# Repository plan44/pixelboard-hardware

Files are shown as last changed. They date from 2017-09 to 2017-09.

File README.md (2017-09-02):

# Pixelboard Hardware

The **Pixelboard** is a 80*40cm lounge table board only 24mm thick, integrating a 10x20 color pixel matrix, 8 touch keys, a linux controller with WiFi and ethernet and even a power supply. All disguised under a dark plexiglass, looking like a regular lounge table until touched...

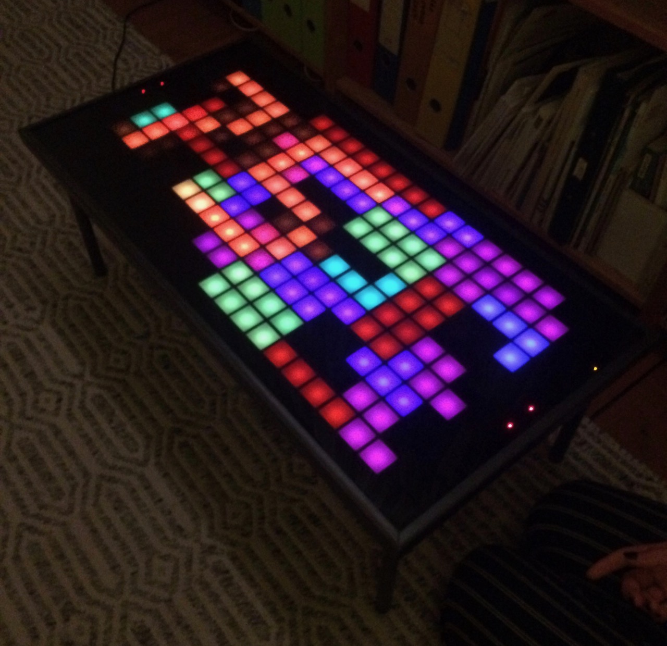
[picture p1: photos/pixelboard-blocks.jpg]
Pixelboard at night

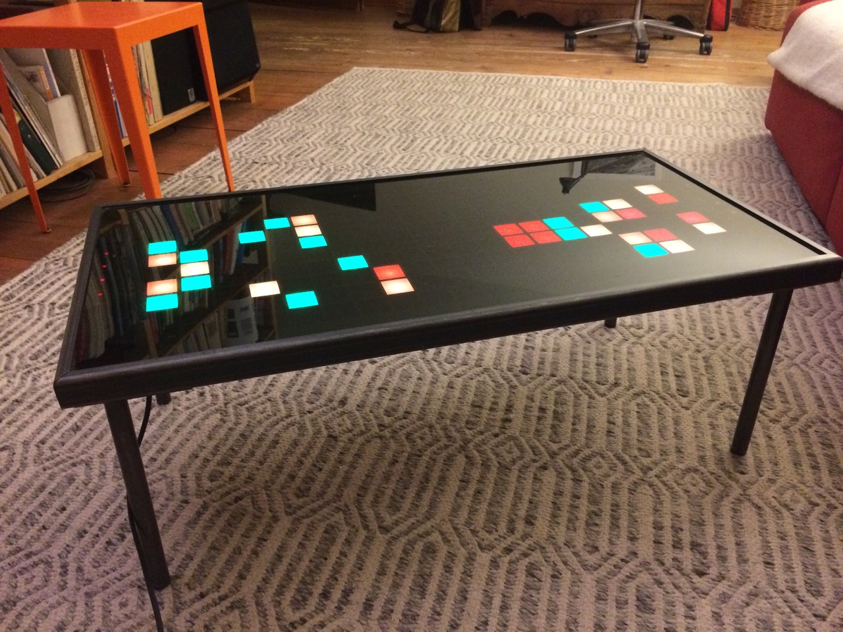
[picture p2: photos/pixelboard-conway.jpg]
Pixelboard daytime


With the current software (see [pixelboardd](https://github.com/plan44/pixelboardd) and [pixelboard-config in plan44-feed](https://github.com/plan44/plan44-feed/tree/for-lede-master/pixelboard-config)) you can play tetris (alone or 2 players each on one end of the board), watch Conway's game of life, let text messages scroll over the surface and display small 10x20 pixel PNG images (via web interface).

The board itself is made of 5 layers of lasered plywood and plexiglass. The construction plan is a [Affinity Designer](https://affinity.serif.com/en-us/designer/) drawing in `mechanics/` and there are SVG exports of the layers in `mechanics/exported SVGs for laser/`.

The pixels are made of 33mm spaced WS2813 LED strips, arranged in a 10*20 matrix, all power and data lines connected by two narrow PCBs (see KiCAD files in `electronics/connectorboard`, PCBs can be [ordered here](https://oshpark.com/shared_projects/2NEbDGZJ)). The board is designed such that it works for both sides of the matrix (flipped over at the far end).

The control board is built around a [Onion Omega2](https://onion.io/omega2/), a MediaTek MT7688 based MIPS board with built-in WiFi, 64MB RAM and 16MB Flash, running a LEDE/OpenWRT Linux based firmware (see [here](https://github.com/plan44/plan44-feed/blob/for-lede-master/pixelboard-config/README.md) for how to build the firmware from scratch). The KiCAD files are in `electronics/controlboard`, PCBs can be [ordered here](https://oshpark.com/shared_projects/cvgoJ8vJ)).

The two identical touch key boards are based on the AT42QT1070 chip for handling the touch detection plus a i2c port extender for connecting the indicator LEDs placed in the middle under each touch key. The KiCAD files are in `electronics/touchboard`, PCBs can be [ordered here](https://oshpark.com/shared_projects/GfQ63cgI)).

And in `photos` there are a few images showing various states of assembling all this:

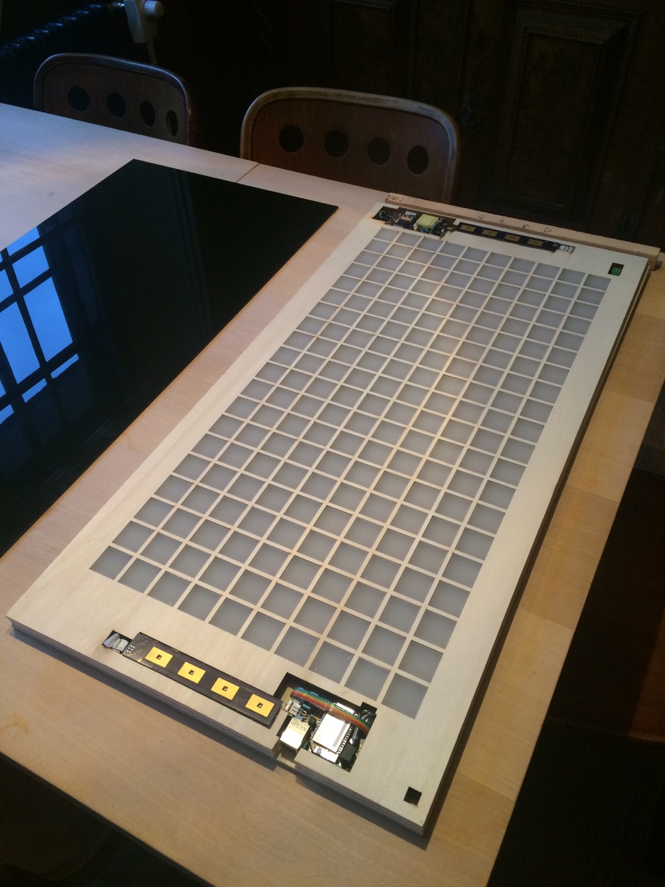
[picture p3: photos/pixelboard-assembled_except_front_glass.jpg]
Without front glass

Front glass removed

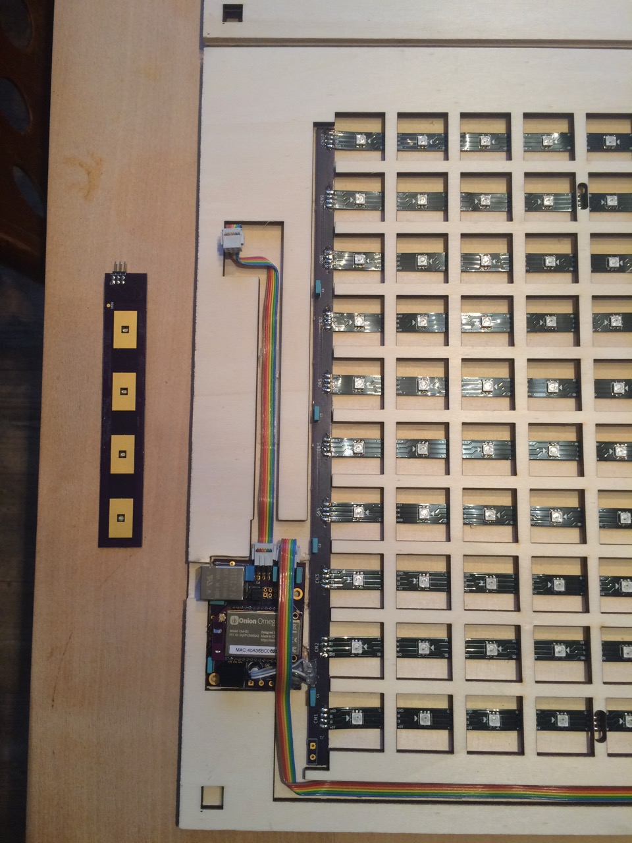
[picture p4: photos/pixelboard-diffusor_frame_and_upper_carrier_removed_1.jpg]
bottom frame only

Controlboard side, just base plate and first lasered frame (lower carrier) keeping the LED matrix, cables, and controlboard in place.

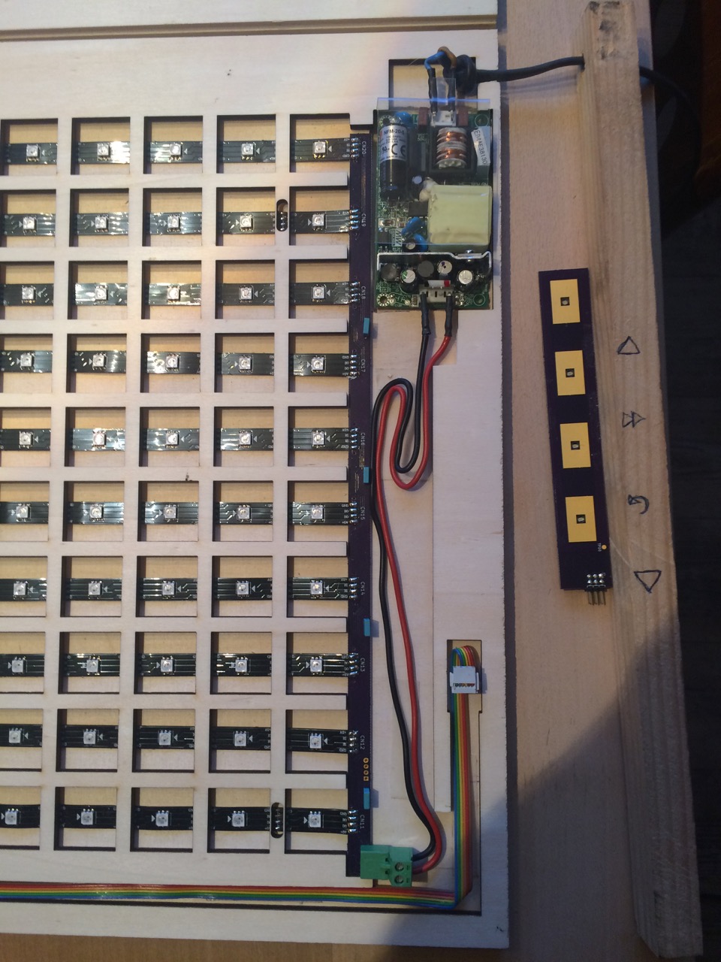
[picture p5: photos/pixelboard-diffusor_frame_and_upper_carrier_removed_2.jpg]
power supply side

Power supply side, base plate and lower carrier.

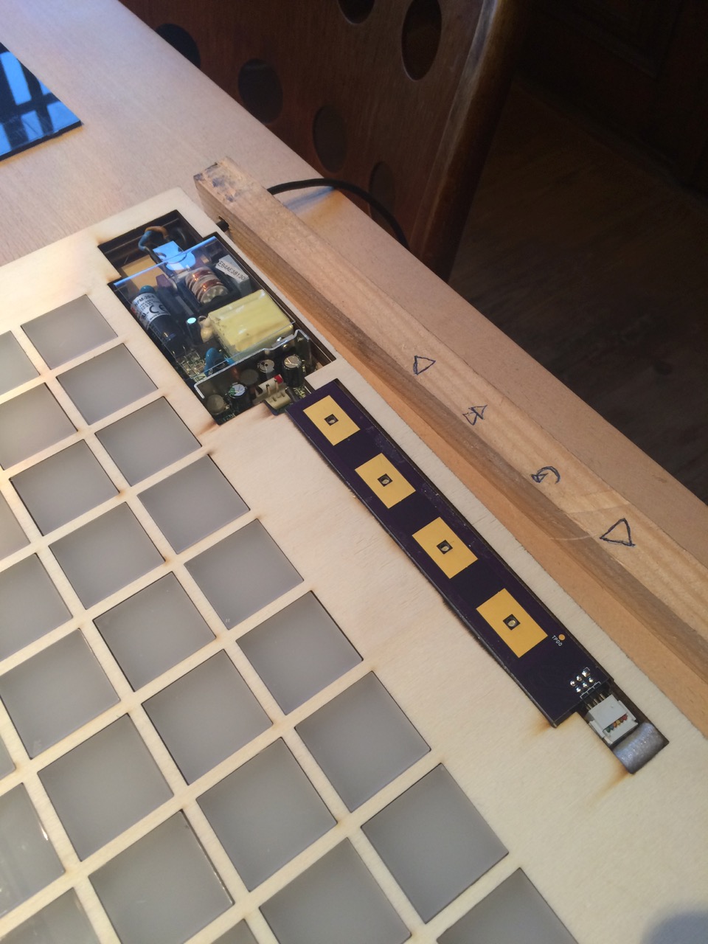
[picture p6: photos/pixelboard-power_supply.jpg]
with touchboard

Power supply side, now with all plywood layers and touchboard mounted.

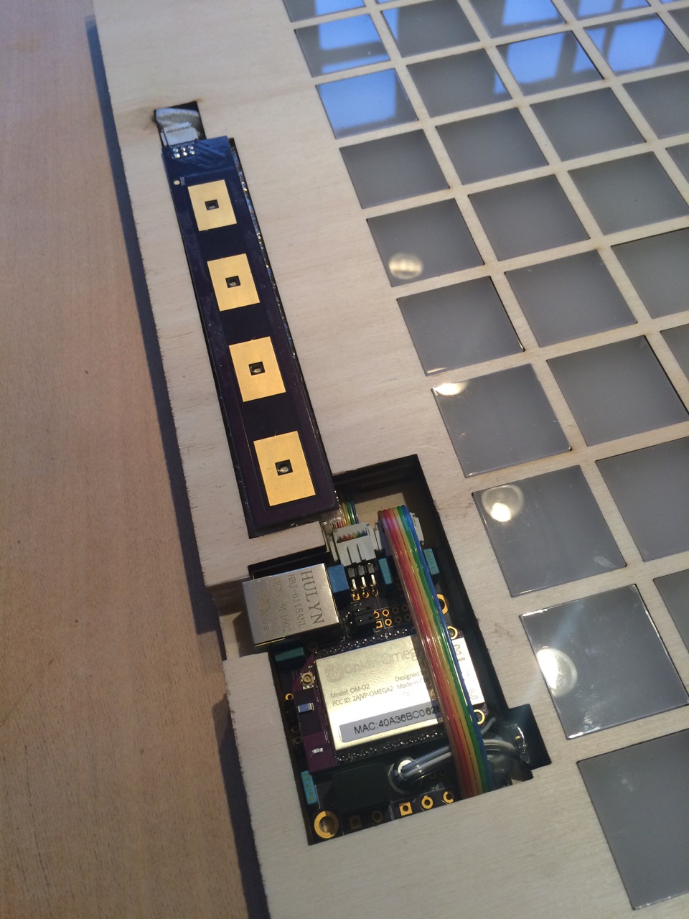
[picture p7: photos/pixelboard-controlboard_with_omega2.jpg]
Controlboard side

Controlboard side, all plywood layers mounted, diffusor plexi sqares inserted, touchboard mounted. Note that this photo does not yet show the hole for a little speaker connected to the MAX98357A i2s amp (but the plan drawings have it).

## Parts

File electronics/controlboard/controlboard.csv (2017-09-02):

Reference | Value | Footprint | Datasheet
U1 | ONION-OMEGA2 | plan44:plan44-ONION-2MM-2X16
J1 | STELVIO-2P-508 | plan44:plan44-STELVIO-2P-508
U2 | Recom_R78Cxx | Converters_DCDC_ACDC:DCDC-Conv_Recom_R-78HBxx-0.5
C5 | 100nF | Capacitors_ThroughHole:C_Rect_L7_W2.5_P5
C3 | 100nF | Capacitors_ThroughHole:C_Rect_L7_W2.5_P5
C4 | 10uF | Capacitors_ThroughHole:C_Radial_D7.5_L11.2_P2.5
P2 | FDI_Cable | Pin_Headers:Pin_Header_Angled_1x06
P3 | CONN_02X03 | Pin_Headers:Pin_Header_Angled_2x03
P4 | CONN_02X03 | Pin_Headers:Pin_Header_Angled_2x03
C1 | 100nF | Capacitors_ThroughHole:C_Rect_L7_W2.5_P5
C2 | 100nF | Capacitors_ThroughHole:C_Rect_L7_W2.5_P5
P1 | CONN_01X04 | Pin_Headers:Pin_Header_Straight_1x04
J3 | HLJ-6115ANL | plan44:plan44-HLJ-6115ANL
P7 | CONN_02X02 | Pin_Headers:Pin_Header_Straight_2x02
C8 | 1uF | Capacitors_ThroughHole:C_Rect_L7_W2.5_P5
R1 | 49.9_1% | Resistors_ThroughHole:Resistor_Horizontal_RM10mm
R2 | 49.9_1% | Resistors_ThroughHole:Resistor_Horizontal_RM10mm
R3 | 49.9_1% | Resistors_ThroughHole:Resistor_Horizontal_RM10mm
R4 | 49.9_1% | Resistors_ThroughHole:Resistor_Horizontal_RM10mm
C6 | 100nF | Capacitors_ThroughHole:C_Rect_L7_W2.5_P5
C7 | 100nF | Capacitors_ThroughHole:C_Rect_L7_W2.5_P5
R5 | 1k | Resistors_ThroughHole:Resistor_Horizontal_RM10mm
R6 | 1k | Resistors_ThroughHole:Resistor_Horizontal_RM10mm
J2 | SBB | plan44:plan44-STELVIO-4P-508
U3 | ADM3485E | SMD_Packages:SOIC-8-N
P6 | CONN_02X03 | Pin_Headers:Pin_Header_Straight_2x03
P5 | CONN_02X05 | Pin_Headers:Pin_Header_Straight_2x05
MH1 | CONN_01X01 | Mounting_Holes:MountingHole_3.2mm_M3_DIN965_Pad
MH2 | CONN_01X01 | Mounting_Holes:MountingHole_3.2mm_M3_DIN965_Pad
U4 | 7400 | Housings_SOIC:SOIC-14_3.9x8.7mm_Pitch1.27mm

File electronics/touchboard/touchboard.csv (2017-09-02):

Reference | Value | Footprint | Datasheet | Family
U1 | AT42QT1070 | SMD_Packages:SOIC-14_N |  | IC
R11 | 4.7k | Resistors_SMD:R_1206_HandSoldering
R2 | 4.7k-20k | Resistors_SMD:R_1206_HandSoldering
R3 | 4.7k | Resistors_SMD:R_1206_HandSoldering
R4 | 4.7k | Resistors_SMD:R_1206_HandSoldering
R5 | 4.7k | Resistors_SMD:R_1206_HandSoldering
R6 | 4.7k | Resistors_SMD:R_1206_HandSoldering
TPD0 | CONN_01X01 | Measurement_Points:Measurement_Point_Round-SMD-Pad_Small
TPD1 | CONN_01X01 | plan44:Touchpad_12x20_with_LED
TPD2 | CONN_01X01 | plan44:Touchpad_12x20_with_LED
TPD3 | CONN_01X01 | plan44:Touchpad_12x20_with_LED
TPD4 | CONN_01X01 | plan44:Touchpad_12x20_with_LED
P1 | CONN_02X03 | Pin_Headers:Pin_Header_Angled_2x03
C1 | C | Capacitors_SMD:C_1206_HandSoldering
R9 | 47k | Resistors_SMD:R_1206_HandSoldering
R13 | 1.2k | Resistors_SMD:R_1206_HandSoldering
R14 | 1.2k | Resistors_SMD:R_1206_HandSoldering
R15 | 1.2k | Resistors_SMD:R_1206_HandSoldering
R16 | 1.2k | Resistors_SMD:R_1206_HandSoldering
U2 | MCP23017 | Housings_SSOP:SSOP-28_5.3x10.2mm_Pitch0.65mm
R1 | 4.7k | Resistors_SMD:R_1206_HandSoldering
D4 | Led_Small | plan44:LED1206_rev_mount
D3 | Led_Small | plan44:LED1206_rev_mount
D2 | Led_Small | plan44:LED1206_rev_mount
D1 | Led_Small | plan44:LED1206_rev_mount
P2 | CONN_01X02 | plan44:CONFIG-PAD-2P
P3 | CONN_01X02 | plan44:CONFIG-PAD-2P

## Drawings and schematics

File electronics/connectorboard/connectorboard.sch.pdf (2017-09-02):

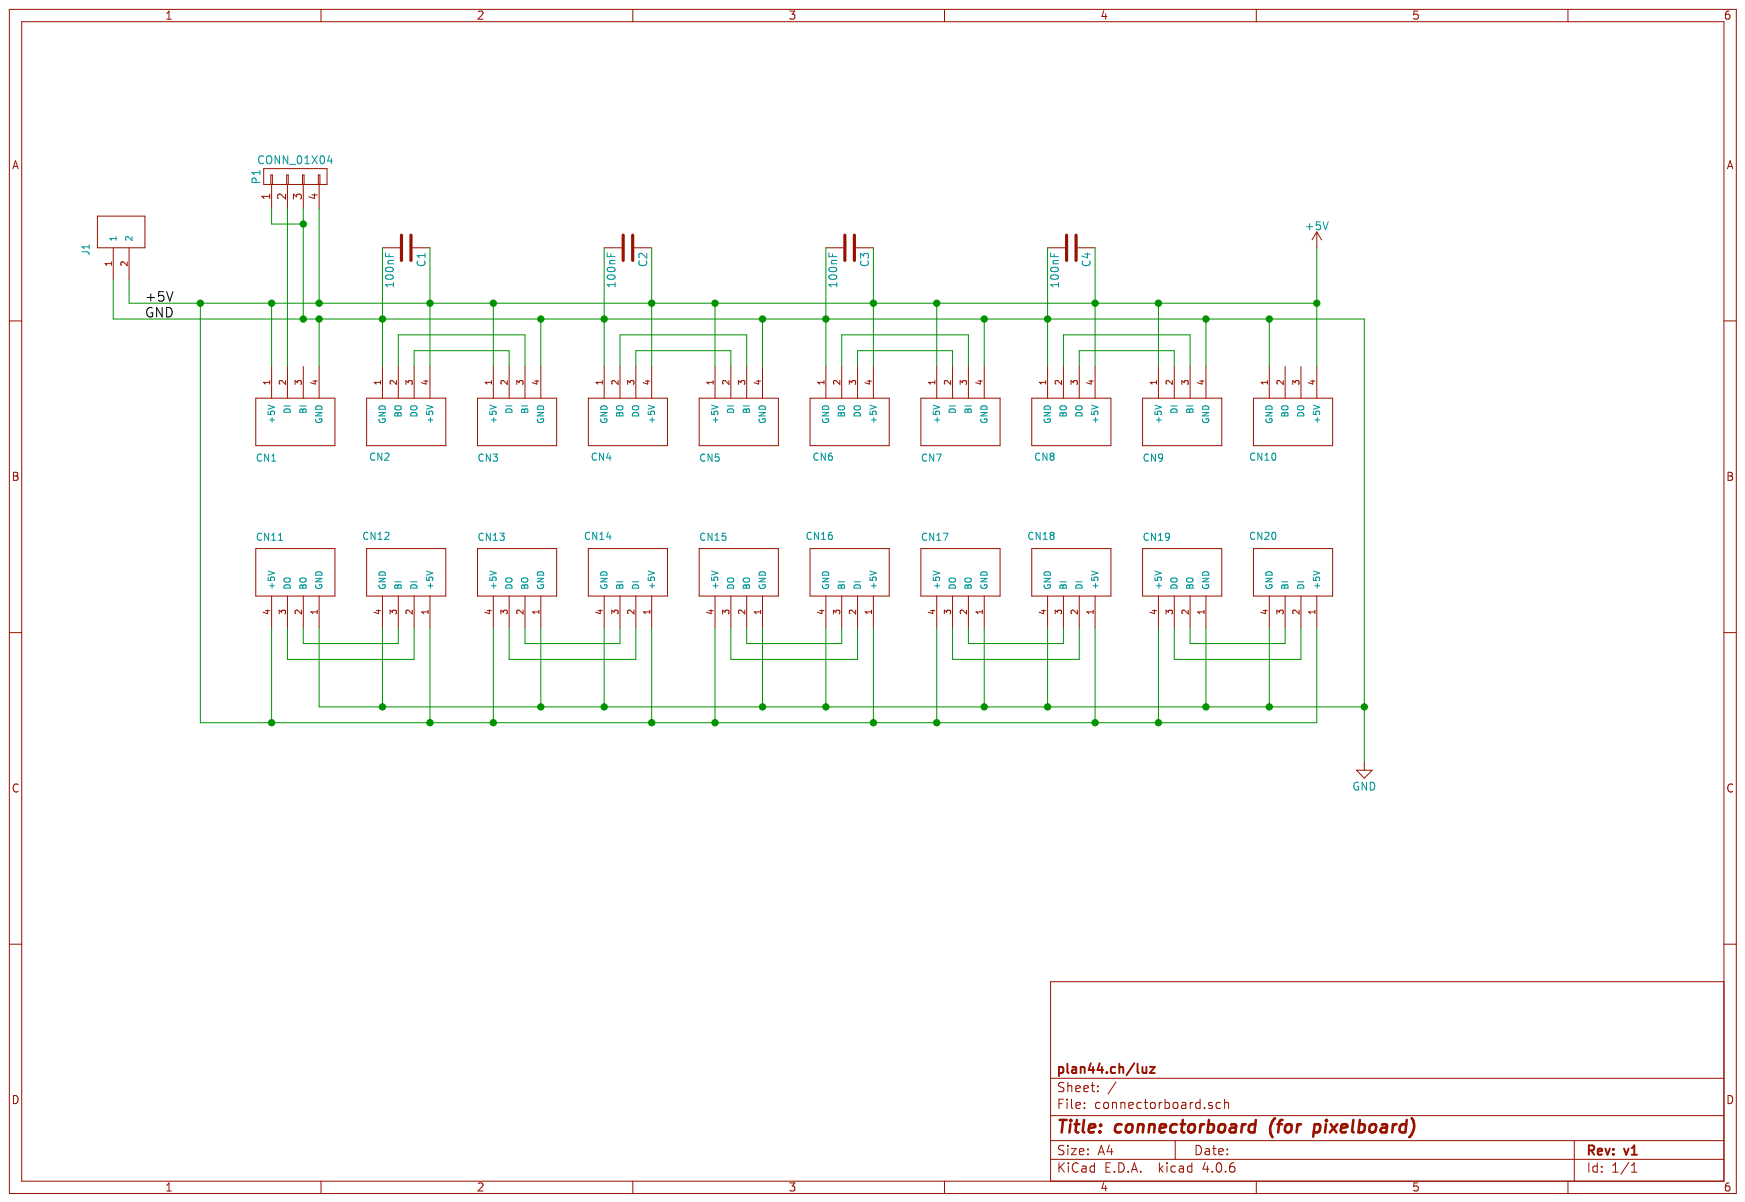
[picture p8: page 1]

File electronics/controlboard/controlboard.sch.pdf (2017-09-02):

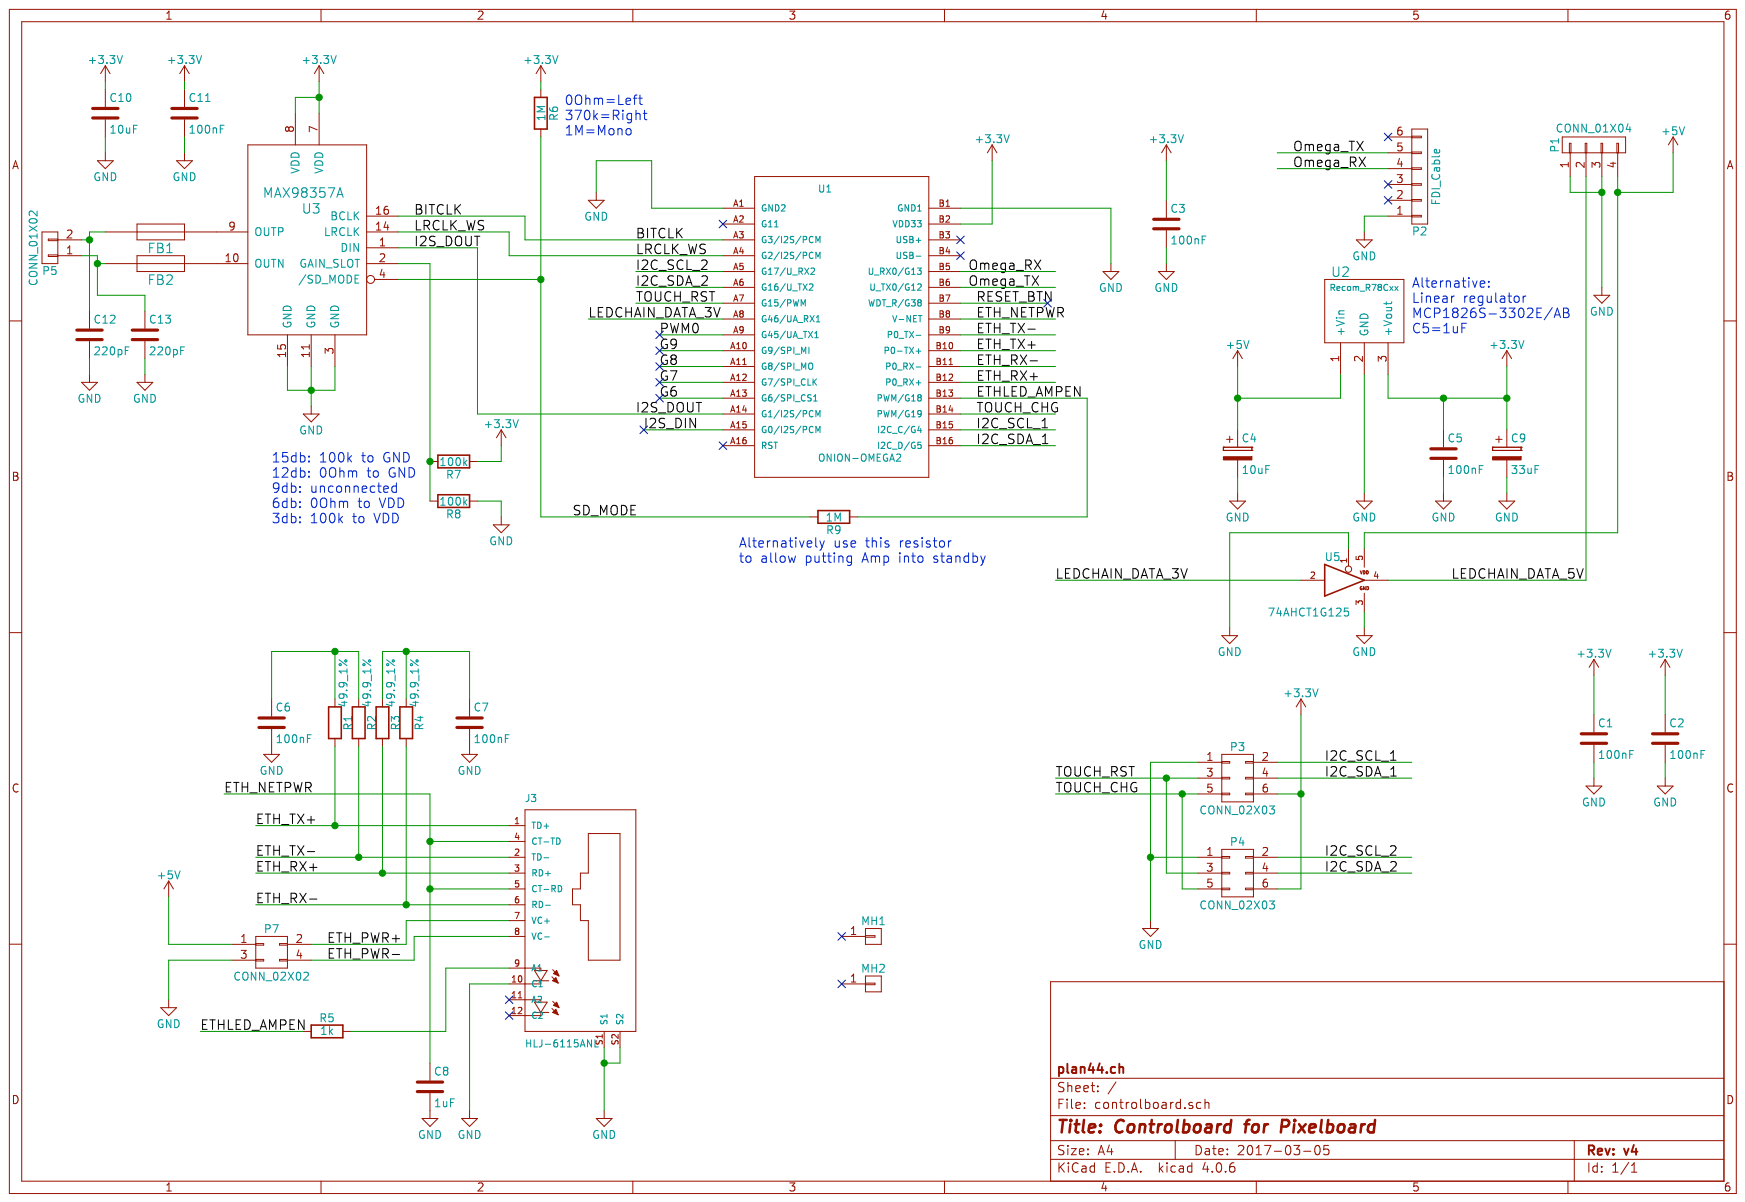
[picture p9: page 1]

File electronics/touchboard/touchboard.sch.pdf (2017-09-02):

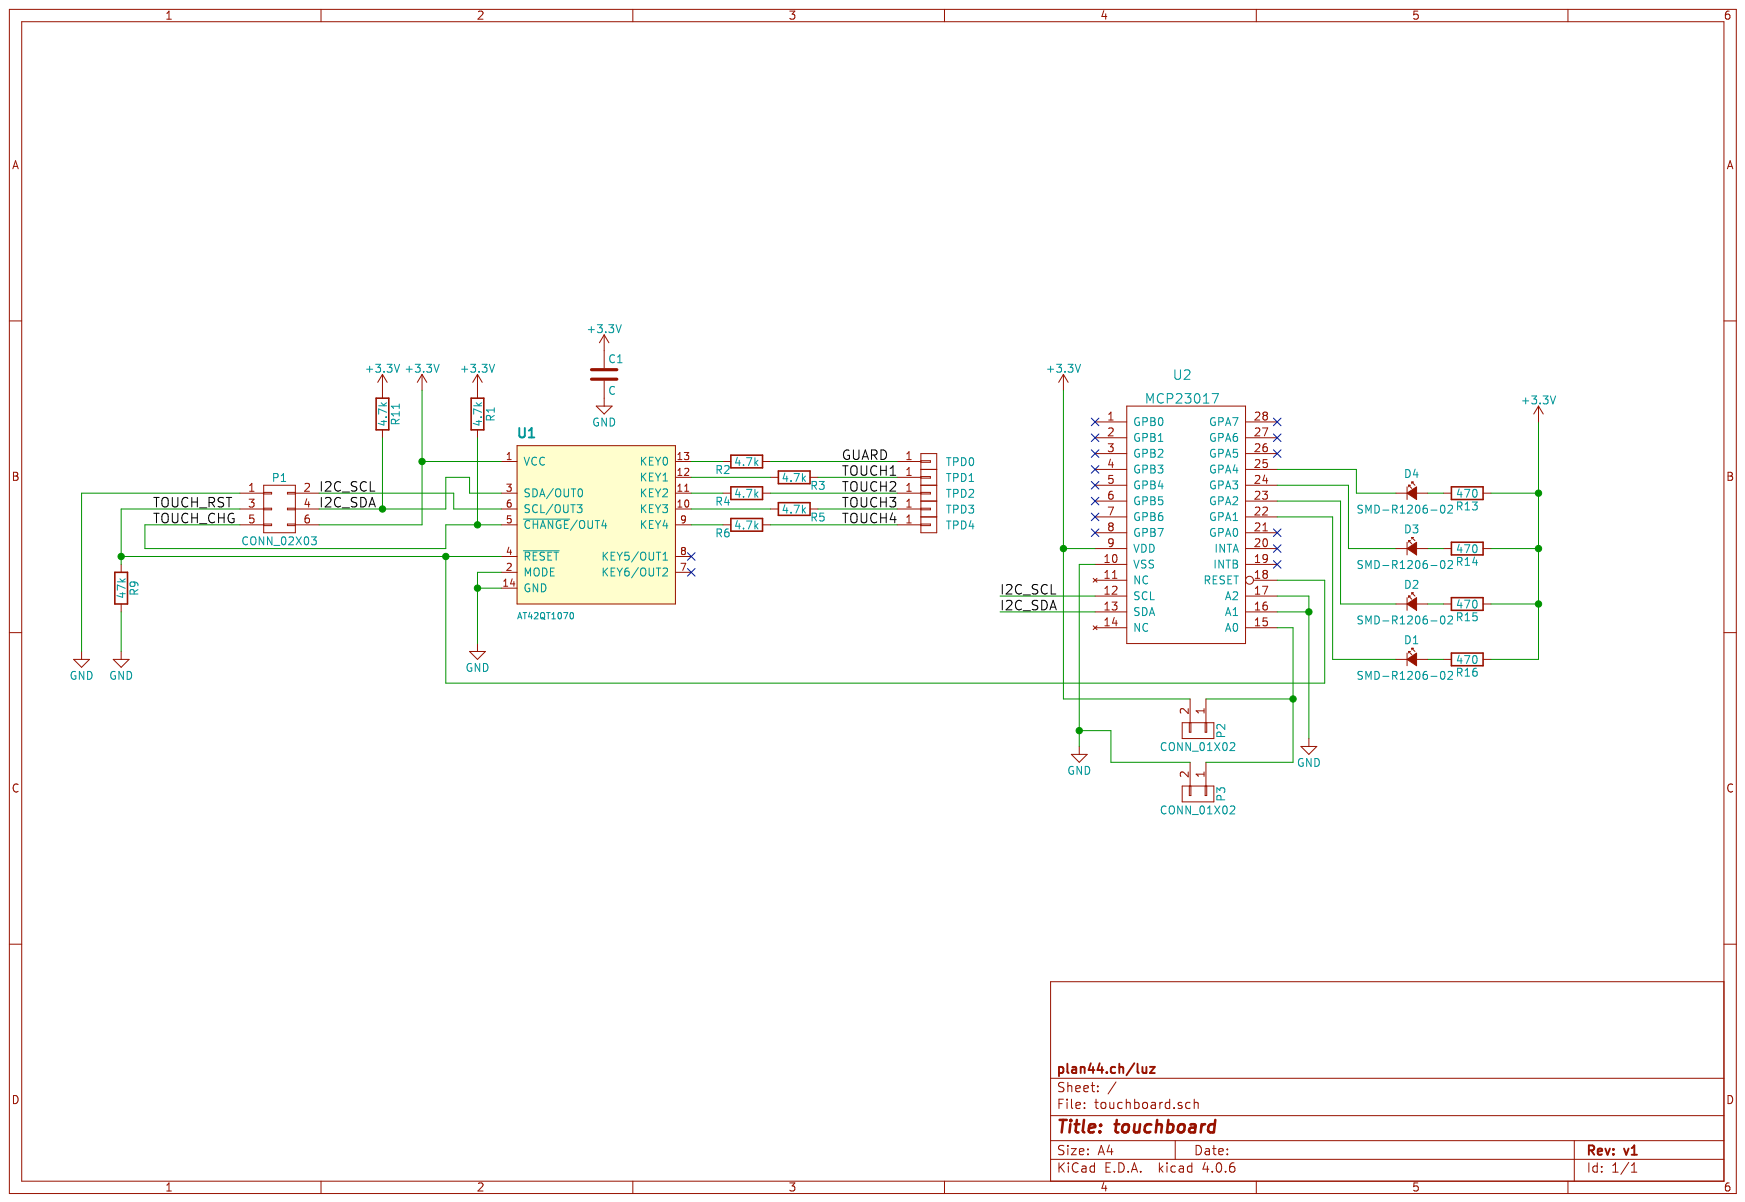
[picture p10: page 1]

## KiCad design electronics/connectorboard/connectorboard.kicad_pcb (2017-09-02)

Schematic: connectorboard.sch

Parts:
C1, C2, C3, C4: 100nF; C_Rect_L7_W2.5_P5
CN1, CN3, CN5, CN7, CN9, CN12, CN14, CN16, CN18, CN20: WS2813-CONN-IN; plan44-WS2813-CONN
CN2, CN4, CN6, CN8, CN10, CN11, CN13, CN15, CN17, CN19: WS2813-CONN-OUT; plan44-WS2813-CONN
J1: STELVIO-2P-508; plan44-STELVIO-2P-508
P1: CONN_01X04; Pin_Header_Straight_1x04

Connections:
+5V: C1.1, C2.1, C3.1, C4.1, CN1.1 (+5V), CN2.4, CN3.1 (+5V), CN4.4, CN5.1 (+5V), CN6.4, CN7.1 (+5V), CN8.4, CN9.1 (+5V), CN10.4, CN11.4, CN12.1 (+5V), CN13.4, CN14.1 (+5V), CN15.4, CN16.1 (+5V), CN17.4, CN18.1 (+5V), CN19.4, CN20.1 (+5V), J1.2, P1.4
GND: C1.2, C2.2, C3.2, C4.2, CN1.4 (GND), CN2.1, CN3.4 (GND), CN4.1, CN5.4 (GND), CN6.1, CN7.4 (GND), CN8.1, CN9.4 (GND), CN10.1, CN11.1, CN12.4 (GND), CN13.1, CN14.4 (GND), CN15.1, CN16.4 (GND), CN17.1, CN18.4 (GND), CN19.1, CN20.4 (GND), J1.1, P1.1, P1.3
unnamed: CN1.2 (DI), P1.2
unnamed: CN2.2, CN3.3 (BI)
unnamed: CN2.3, CN3.2 (DI)
unnamed: CN4.2, CN5.3 (BI)
unnamed: CN4.3, CN5.2 (DI)
unnamed: CN6.2, CN7.3 (BI)
unnamed: CN6.3, CN7.2 (DI)
unnamed: CN8.2, CN9.3 (BI)
unnamed: CN8.3, CN9.2 (DI)
unnamed: CN11.2, CN12.3 (BI)
unnamed: CN11.3, CN12.2 (DI)
unnamed: CN13.2, CN14.3 (BI)
unnamed: CN13.3, CN14.2 (DI)
unnamed: CN15.2, CN16.3 (BI)
unnamed: CN15.3, CN16.2 (DI)
unnamed: CN17.2, CN18.3 (BI)
unnamed: CN17.3, CN18.2 (DI)
unnamed: CN19.2, CN20.3 (BI)
unnamed: CN19.3, CN20.2 (DI)

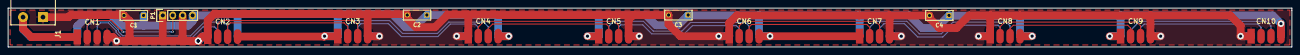
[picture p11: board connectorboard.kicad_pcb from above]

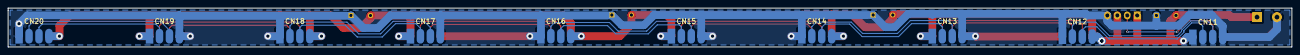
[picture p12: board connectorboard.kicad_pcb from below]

Board: 2 copper layers, 327.7 x 9.9 mm, 26 parts (10 on the bottom side), 21 nets.

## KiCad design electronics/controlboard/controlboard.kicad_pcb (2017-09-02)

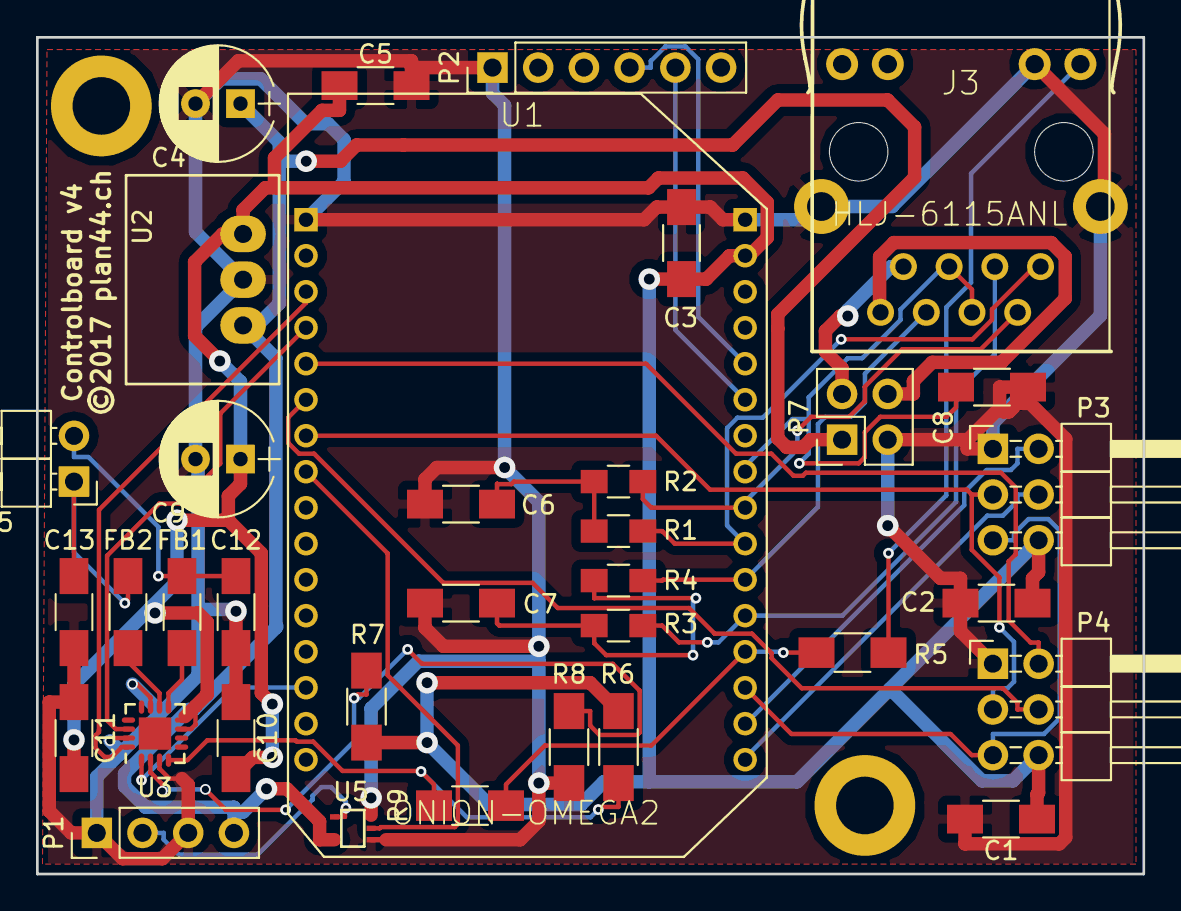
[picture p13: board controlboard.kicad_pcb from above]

Board: 2 copper layers, 61.5 x 46.5 mm, 37 parts (0 on the bottom side), 33 nets.

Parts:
C1, C2, C3, C5, C6, C7, C11: 100nF; C_1206_HandSoldering
C4: 10uF; CP_Radial_D6.3mm_P2.50mm
C8: 1uF; C_1206_HandSoldering
C9: 33uF; CP_Radial_D6.3mm_P2.50mm
C10: 10uF; C_1206_HandSoldering
C12, C13: 220pF; C_1206_HandSoldering
FB1, FB2: Ferritebead; C_1206_HandSoldering
J3: HLJ-6115ANL; plan44-HLJ-6115ANL
MH1, MH2: CONN_01X01; MountingHole_3.2mm_M3_DIN965_Pad
P1: CONN_01X04; Pin_Header_Straight_1x04_Pitch2.54mm
P2: FDI_Cable; Pin_Header_Straight_1x06_Pitch2.54mm
P3, P4: CONN_02X03; Pin_Header_Angled_2x03_Pitch2.54mm
P5: CONN_01X02; Pin_Header_Angled_1x02_Pitch2.54mm
P7: CONN_02X02; Pin_Header_Straight_2x02_Pitch2.54mm
R1, R2, R3, R4: 49.9_1%; R_0805_HandSoldering
R5: 1k; R_1206_HandSoldering
R6, R9: 1M; R_1206_HandSoldering
R7, R8: 100k; R_1206_HandSoldering
U1: ONION-OMEGA2; plan44-ONION-2MM-2X16
U2: Recom_R78Cxx; plan44-Recom-R78Cxx
U3: MAX98357A; QFN-16-1EP_3x3mm_Pitch0.5mm
U5: 74AHCT1G125; SOT-353

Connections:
+3V3: C1.1, C2.1, C3.1, C5.1, C9.1, C10.1, C11.1, P3.6, P4.6, R6.1, R7.1, U1.B2, U2.3, U3.7, U3.8
+5V: C4.1, P1.4, P7.1, U2.1, U5.5
/BITCLK: U1.A3, U3.16
/ETHLED_AMPEN: R5.1, R9.1, U1.B13
/ETH_NETPWR: C8.1, J3.4, J3.5, U1.B8
/ETH_PWR+: J3.7, P7.2
/ETH_PWR-: J3.8, P7.4
/ETH_RX+: J3.3, R3.2, U1.B12
/ETH_RX-: J3.6, R4.2, U1.B11
/ETH_TX+: J3.1, R1.2, U1.B10
/ETH_TX-: J3.2, R2.2, U1.B9
/I2C_SCL_1: P3.2, U1.B15
/I2C_SCL_2: P4.2, U1.A5
/I2C_SDA_1: P3.4, U1.B16
/I2C_SDA_2: P4.4, U1.A6
/I2S_DOUT: U1.A14, U3.1
/LEDCHAIN_DATA_3V: U1.A8, U5.2
/LEDCHAIN_DATA_5V: P1.2, U5.4
/LRCLK_WS: U1.A4, U3.14
/Omega_RX: P2.4, U1.B5
/Omega_TX: P2.5, U1.B6
/SD_MODE: R6.2, R9.2, U3.4
/TOUCH_CHG: P3.5, P4.5, U1.B14
/TOUCH_RST: P3.3, P4.3, U1.A7
GND: C1.2, C2.2, C3.2, C4.2, C5.2, C6.2, C7.2, C8.2, C9.2, C10.2, C11.2, C12.2, C13.2, J3.10, J3.S1, J3.S2, P1.1, P1.3, P2.1, P3.1, P4.1, P7.3, R8.1, U1.A1, U1.B1, U2.2, U3.3, U3.11, U3.15, U5.1, U5.3
unnamed: C6.1, R1.1, R2.1
unnamed: C7.1, R3.1, R4.1
unnamed: C12.1, FB1.2, P5.2
unnamed: C13.1, FB2.2, P5.1
unnamed: FB1.1, U3.9
unnamed: FB2.1, U3.10
unnamed: J3.9, R5.2
unnamed: R7.2, R8.2, U3.2

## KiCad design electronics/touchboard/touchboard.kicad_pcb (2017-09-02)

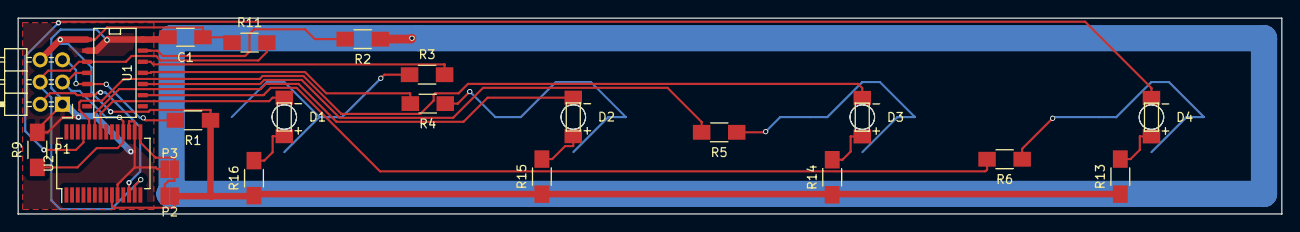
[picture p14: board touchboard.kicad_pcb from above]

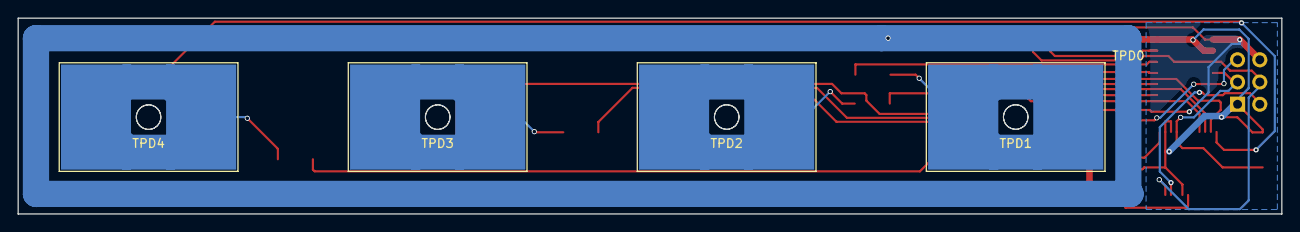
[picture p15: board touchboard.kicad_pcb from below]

Board: 2 copper layers, 144.3 x 22.4 mm, 27 parts (5 on the bottom side), 25 nets.

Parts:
C1: C; C_1206_HandSoldering
D1, D2, D3, D4: Led_Small; LED1206_rev_mount
P1: CONN_02X03; Pin_Header_Angled_2x03
P2, P3: CONN_01X02; CONFIG-PAD-2P
R1, R3, R4, R5, R6, R11: 4.7k; R_1206_HandSoldering
R2: 4.7k-20k; R_1206_HandSoldering
R9: 47k; R_1206_HandSoldering
R13, R14, R15, R16: 1.2k; R_1206_HandSoldering
TPD0: CONN_01X01; Measurement_Point_Round-SMD-Pad_Small
TPD1, TPD2, TPD3, TPD4: CONN_01X01; Touchpad_12x20_with_LED
U1: AT42QT1070; SOIC-14_N
U2: MCP23017; SSOP-28_5.3x10.2mm_Pitch0.65mm

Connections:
+3V3: C1.1, P1.6, P2.2, R1.1, R11.1, R13.1, R14.1, R15.1, R16.1, U1.1, U2.9
/GUARD: R2.1, TPD0.1
/I2C_SCL: P1.2, U1.6, U2.12
/I2C_SDA: P1.4, R11.2, U1.3, U2.13
/TOUCH1: R3.1, TPD1.1
/TOUCH2: R4.1, TPD2.1
/TOUCH3: R5.1, TPD3.1
/TOUCH4: R6.1, TPD4.1
/TOUCH_CHG: P1.5, R1.2, U1.5
/TOUCH_RST: P1.3, R9.1, U1.4, U2.18
GND: C1.2, P1.1, P3.2, R9.2, U1.2, U1.14, U2.10, U2.16, U2.17
unnamed: D1.1, U2.22
unnamed: D1.2, R16.2
unnamed: D2.1, U2.23
unnamed: D2.2, R15.2
unnamed: D3.1, U2.24
unnamed: D3.2, R14.2
unnamed: D4.1, U2.25
unnamed: D4.2, R13.2
unnamed: P2.1, P3.1, U2.15
unnamed: R2.2, U1.13
unnamed: R3.2, U1.12
unnamed: R4.2, U1.11
unnamed: R5.2, U1.10
unnamed: R6.2, U1.9

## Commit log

2017-09-02 Initial checkin, not complete yet
    [connectorboard.dsn, connectorboard.kicad_pcb, connectorboard.sch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]
2017-09-02 KiCAD: correced library paths to reach the plan44-kicad library (when cloned from github into the same parent as pixelboard-hardware)
    [connectorboard.sch, controlboard.sch, touchboard.sch]
2017-09-02 Added PDFs of schematics

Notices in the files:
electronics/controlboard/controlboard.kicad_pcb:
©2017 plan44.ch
